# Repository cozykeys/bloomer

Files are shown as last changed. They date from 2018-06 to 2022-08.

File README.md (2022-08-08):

# CozyKeys Bloomer

This repository contains the design files for the CozyKeys Bloomer, an 87-key
ergonomic mechanical keyboard.

This keyboard has undergone several revisions and name changes. Previous names
were *Atreus87* and *Ergo87* and artifacts of these may still be present in the
repository.

Bloomer

## Firmware

- [Bloomer rev2](https://github.com/cozykeys/qmk_firmware/tree/bloomer_v2)
- [Bloomer rev3](https://github.com/cozykeys/qmk_firmware/tree/bloomer_v3)

## Project Status

### rev0

The first revision of the board was hand-wired and built as a proof of concept
to ensure that the layout is comfortable.

### rev1

The second revision added a PCB and a complete redesign of the case so that the
PCB would fit accurately.

This initial PCB was functional but lacked any RGB support. It also had a few
issues:
- When placing the ItsyBitsy upside down to reduce the height needed between
  the switch plate and bottom plate, there is no easy way to access RST
- Switch footprints were "flippable" which was misleading as the controller
  pinout only supported a single orientation

### rev2

The second revision added several features and fixes:
- Dedicated reset button with the case updated to make this accessible
- Single orientation switch footprints
- RGB underglow support

[Rev2 Build Guide](./revisions/rev2/README.md)

### rev3 (REDACTED)

See: [v3.0 README](./v3.0/README.md)

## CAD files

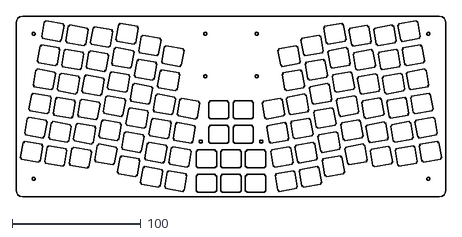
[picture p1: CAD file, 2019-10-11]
revisions/rev3.1/bloomer_switch_plate_v3_1.dxf
333.7 x 140.0

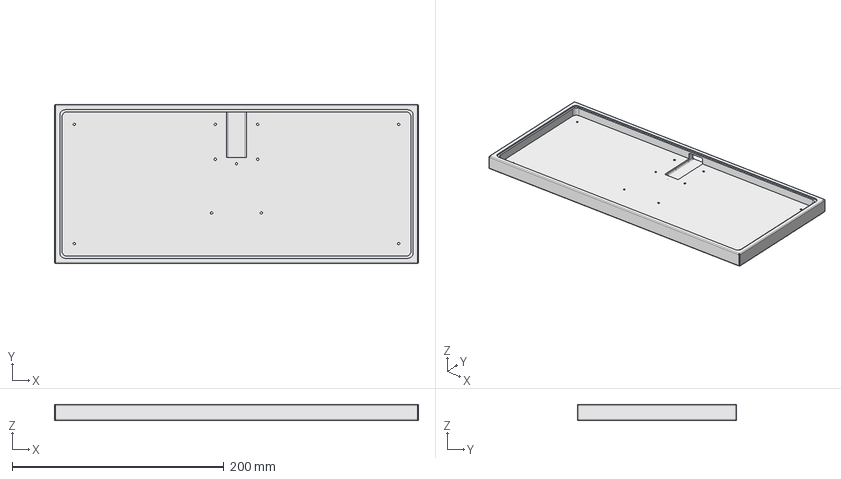
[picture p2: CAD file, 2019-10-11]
v3.0/case/bloomer_case.FCStd
344.2 x 150.5 x 15.5 mm

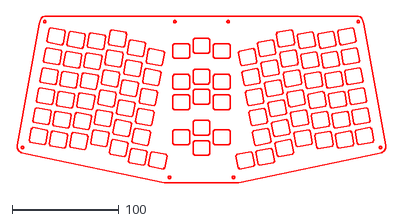
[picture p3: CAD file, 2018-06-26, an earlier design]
revisions/rev0/Sculpteo/Ergo87_Top_2.dxf
347.5 x 156.0

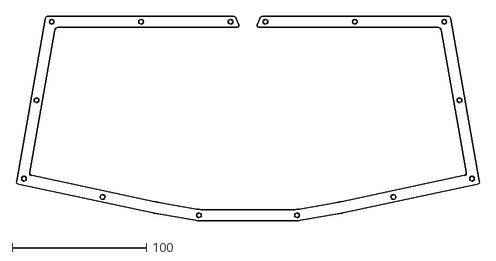
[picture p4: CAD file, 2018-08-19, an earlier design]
revisions/rev2/case_middle_plate_rev2.dxf
345.5 x 152.7

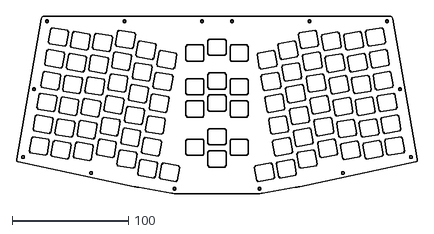
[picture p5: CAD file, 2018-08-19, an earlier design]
revisions/rev2/case_switch_plate_rev2.dxf
345.5 x 152.7

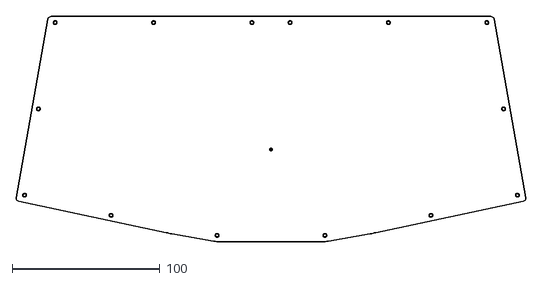
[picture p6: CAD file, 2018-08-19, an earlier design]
revisions/rev2/case_bottom_plate_rev2.dxf
345.5 x 152.7

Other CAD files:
revisions/rev3.1/bloomer_case.step
v3.0/case/case_switch_plate.dxf
revisions/rev3.1/bloomer_case.stl

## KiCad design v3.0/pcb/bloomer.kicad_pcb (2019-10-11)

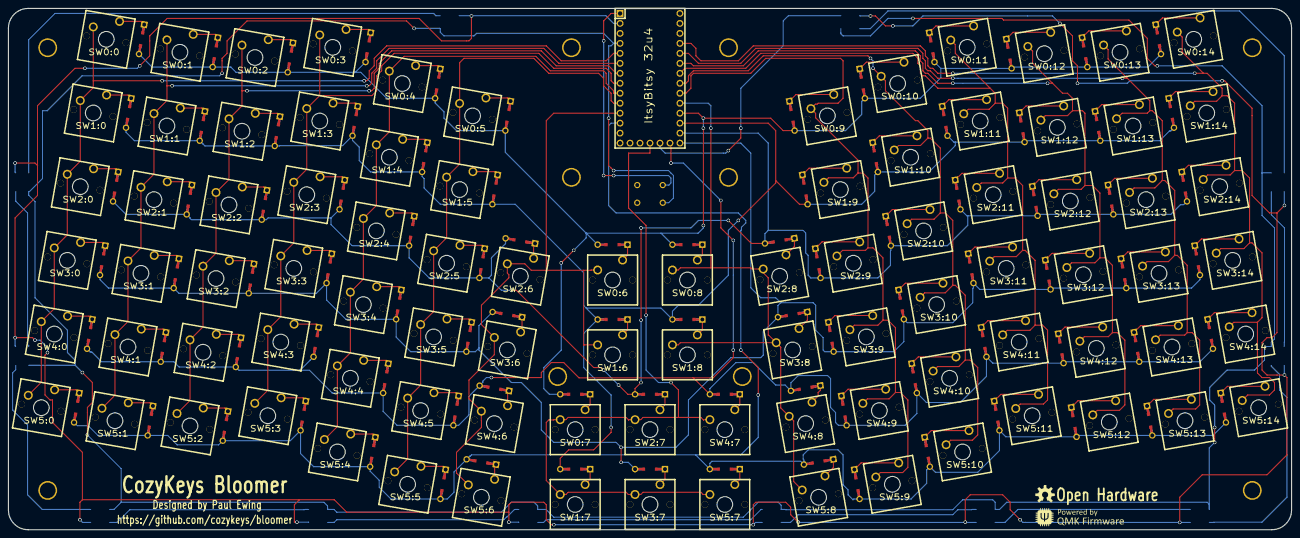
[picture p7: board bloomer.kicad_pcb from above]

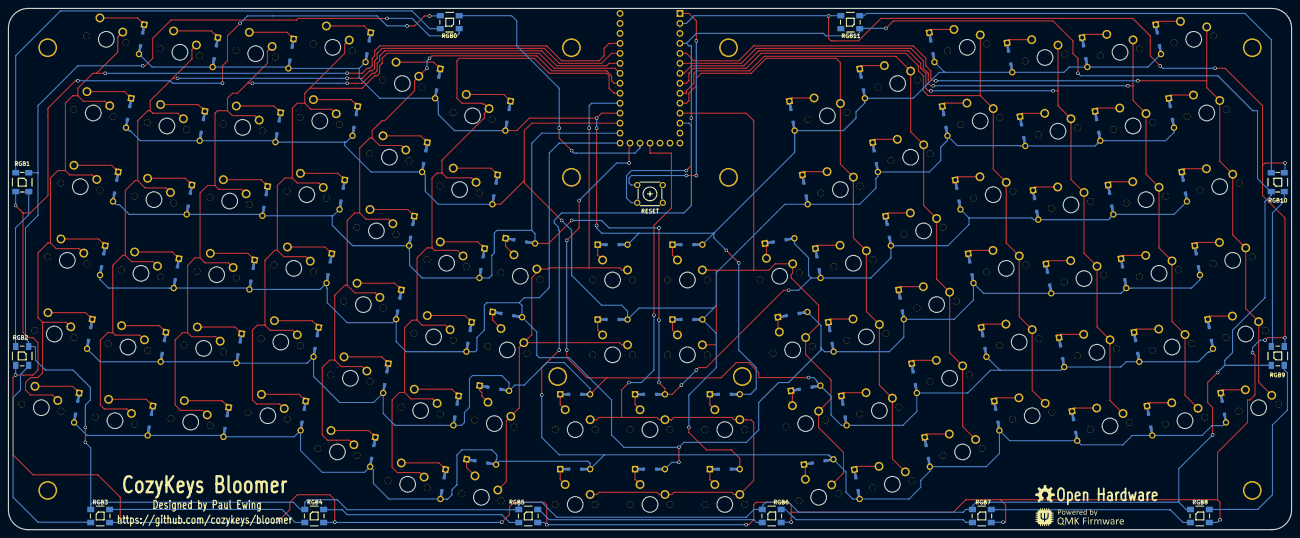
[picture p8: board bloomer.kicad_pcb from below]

Board: 2 copper layers, 326.7 x 132.7 mm, 204 parts (13 on the bottom side), 126 nets.

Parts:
D0:0, D0:1, D0:2, D0:3, D0:4, D0:5, D0:6, D0:7, D0:8, D0:9, D0:10, D0:11, D0:12, D0:13, D0:14, D1:0, D1:1, D1:2, D1:3, D1:4, D1:5, D1:6, D1:7, D1:8, D1:9, D1:10, D1:11, D1:12, D1:13, D1:14, D2:0, D2:1, D2:2, D2:3, D2:4, D2:5, D2:6, D2:7, D2:8, D2:9, D2:10, D2:11, D2:12, D2:13, D2:14, D3:0, D3:1, D3:2, D3:3, D3:4, D3:5, D3:6, D3:7, D3:8, D3:9, D3:10, D3:11, D3:12, D3:13, D3:14, D4:0, D4:1, D4:2, D4:3, D4:4, D4:5, D4:6, D4:7, D4:8, D4:9, D4:10, D4:11, D4:12, D4:13, D4:14, D5:0, D5:1, D5:2, D5:3, D5:4, D5:5, D5:6, D5:7, D5:8, D5:9, D5:10, D5:11, D5:12, D5:13, D5:14: DIODE
HOLE_M3, HOLE_M3#2, HOLE_M3#3, HOLE_M3#4, HOLE_M3#5, HOLE_M3#6, HOLE_M3#7, HOLE_M3#8, HOLE_M3#9, HOLE_M3#10: VAL**; HOLE_M3
ItsyBitsy 32u4: ItsyBitsy
RESET: VAL**; B3F-10XX
RGB0, RGB1, RGB2, RGB3, RGB4, RGB5, RGB6, RGB7, RGB8, RGB9, RGB10, RGB11: VAL**; WS2812B
SW0:0, SW0:1, SW0:2, SW0:3, SW0:4, SW0:5, SW0:6, SW0:7, SW0:8, SW0:9, SW0:10, SW0:11, SW0:12, SW0:13, SW0:14, SW1:0, SW1:1, SW1:2, SW1:3, SW1:4, SW1:5, SW1:6, SW1:7, SW1:8, SW1:9, SW1:10, SW1:11, SW1:12, SW1:13, SW1:14, SW2:0, SW2:1, SW2:2, SW2:3, SW2:4, SW2:5, SW2:6, SW2:7, SW2:8, SW2:9, SW2:10, SW2:11, SW2:12, SW2:13, SW2:14, SW3:0, SW3:1, SW3:2, SW3:3, SW3:4, SW3:5, SW3:6, SW3:7, SW3:8, SW3:9, SW3:10, SW3:11, SW3:12, SW3:13, SW3:14, SW4:0, SW4:1, SW4:2, SW4:3, SW4:4, SW4:5, SW4:6, SW4:7, SW4:8, SW4:9, SW4:10, SW4:11, SW4:12, SW4:13, SW4:14, SW5:0, SW5:1, SW5:2, SW5:3, SW5:4, SW5:5, SW5:6, SW5:7, SW5:8, SW5:9, SW5:10, SW5:11, SW5:12, SW5:13, SW5:14: MX_SWITCH

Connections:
5V: ItsyBitsy 32u4.2, RGB0.3, RGB1.3, RGB2.3, RGB3.3, RGB4.3, RGB5.3, RGB6.3, RGB7.3, RGB8.3, RGB9.3, RGB10.3, RGB11.3
GND: ItsyBitsy 32u4.4, RESET.2, RGB0.1, RGB1.1, RGB2.1, RGB3.1, RGB4.1, RGB5.1, RGB6.1, RGB7.1, RGB8.1, RGB9.1, RGB10.1, RGB11.1
N-RGB-D0: ItsyBitsy 32u4.18, RGB0.2
N-RGB-D1: RGB0.4, RGB1.2
N-RGB-D2: RGB1.4, RGB2.2
N-RGB-D3: RGB2.4, RGB3.2
N-RGB-D4: RGB3.4, RGB4.2
N-RGB-D5: RGB4.4, RGB5.2
N-RGB-D6: RGB5.4, RGB6.2
N-RGB-D7: RGB6.4, RGB7.2
N-RGB-D8: RGB7.4, RGB8.2
N-RGB-D9: RGB8.4, RGB9.2
N-RGB-D10: RGB9.4, RGB10.2
N-RGB-D11: RGB10.4, RGB11.2
N-col-0: ItsyBitsy 32u4.5, SW0:0.2, SW1:0.2, SW2:0.2, SW3:0.2, SW4:0.2, SW5:0.2
N-col-1: ItsyBitsy 32u4.6, SW0:1.2, SW1:1.2, SW2:1.2, SW3:1.2, SW4:1.2, SW5:1.2
N-col-2: ItsyBitsy 32u4.7, SW0:2.2, SW1:2.2, SW2:2.2, SW3:2.2, SW4:2.2, SW5:2.2
N-col-3: ItsyBitsy 32u4.8, SW0:3.2, SW1:3.2, SW2:3.2, SW3:3.2, SW4:3.2, SW5:3.2
N-col-4: ItsyBitsy 32u4.9, SW0:4.2, SW1:4.2, SW2:4.2, SW3:4.2, SW4:4.2, SW5:4.2
N-col-5: ItsyBitsy 32u4.10, SW0:5.2, SW1:5.2, SW2:5.2, SW3:5.2, SW4:5.2, SW5:5.2
N-col-6: ItsyBitsy 32u4.11, SW0:6.2, SW1:6.2, SW2:6.2, SW3:6.2, SW4:6.2, SW5:6.2
N-col-7: ItsyBitsy 32u4.17, SW0:7.2, SW1:7.2, SW2:7.2, SW3:7.2, SW4:7.2, SW5:7.2
N-col-8: ItsyBitsy 32u4.24, SW0:8.2, SW1:8.2, SW2:8.2, SW3:8.2, SW4:8.2, SW5:8.2
N-col-9: ItsyBitsy 32u4.25, SW0:9.2, SW1:9.2, SW2:9.2, SW3:9.2, SW4:9.2, SW5:9.2
N-col-10: ItsyBitsy 32u4.26, SW0:10.2, SW1:10.2, SW2:10.2, SW3:10.2, SW4:10.2, SW5:10.2
N-col-11: ItsyBitsy 32u4.27, SW0:11.2, SW1:11.2, SW2:11.2, SW3:11.2, SW4:11.2, SW5:11.2
N-col-12: ItsyBitsy 32u4.28, SW0:12.2, SW1:12.2, SW2:12.2, SW3:12.2, SW4:12.2, SW5:12.2
N-col-13: ItsyBitsy 32u4.29, SW0:13.2, SW1:13.2, SW2:13.2, SW3:13.2, SW4:13.2, SW5:13.2
N-col-14: ItsyBitsy 32u4.30, SW0:14.2, SW1:14.2, SW2:14.2, SW3:14.2, SW4:14.2, SW5:14.2
N-diode-0-0: D0:0.2, SW0:0.1
N-diode-0-1: D0:1.2, SW0:1.1
N-diode-0-2: D0:2.2, SW0:2.1
N-diode-0-3: D0:3.2, SW0:3.1
N-diode-0-4: D0:4.2, SW0:4.1
N-diode-0-5: D0:5.2, SW0:5.1
N-diode-0-6: D0:6.2, SW0:6.1
N-diode-0-7: D0:7.2, SW0:7.1
N-diode-0-8: D0:8.2, SW0:8.1
N-diode-0-9: D0:9.2, SW0:9.1
N-diode-0-10: D0:10.2, SW0:10.1
N-diode-0-11: D0:11.2, SW0:11.1
N-diode-0-12: D0:12.2, SW0:12.1
N-diode-0-13: D0:13.2, SW0:13.1
N-diode-0-14: D0:14.2, SW0:14.1
N-diode-1-0: D1:0.2, SW1:0.1
N-diode-1-1: D1:1.2, SW1:1.1
N-diode-1-2: D1:2.2, SW1:2.1
N-diode-1-3: D1:3.2, SW1:3.1
N-diode-1-4: D1:4.2, SW1:4.1
N-diode-1-5: D1:5.2, SW1:5.1
N-diode-1-6: D1:6.2, SW1:6.1
N-diode-1-7: D1:7.2, SW1:7.1
N-diode-1-8: D1:8.2, SW1:8.1
N-diode-1-9: D1:9.2, SW1:9.1
N-diode-1-10: D1:10.2, SW1:10.1
N-diode-1-11: D1:11.2, SW1:11.1
N-diode-1-12: D1:12.2, SW1:12.1
N-diode-1-13: D1:13.2, SW1:13.1
N-diode-1-14: D1:14.2, SW1:14.1
N-diode-2-0: D2:0.2, SW2:0.1
N-diode-2-1: D2:1.2, SW2:1.1
N-diode-2-2: D2:2.2, SW2:2.1
N-diode-2-3: D2:3.2, SW2:3.1
N-diode-2-4: D2:4.2, SW2:4.1
N-diode-2-5: D2:5.2, SW2:5.1
N-diode-2-6: D2:6.2, SW2:6.1
N-diode-2-7: D2:7.2, SW2:7.1
N-diode-2-8: D2:8.2, SW2:8.1
N-diode-2-9: D2:9.2, SW2:9.1
N-diode-2-10: D2:10.2, SW2:10.1
N-diode-2-11: D2:11.2, SW2:11.1
N-diode-2-12: D2:12.2, SW2:12.1
N-diode-2-13: D2:13.2, SW2:13.1
N-diode-2-14: D2:14.2, SW2:14.1
N-diode-3-0: D3:0.2, SW3:0.1
N-diode-3-1: D3:1.2, SW3:1.1
N-diode-3-2: D3:2.2, SW3:2.1
N-diode-3-3: D3:3.2, SW3:3.1
N-diode-3-4: D3:4.2, SW3:4.1
N-diode-3-5: D3:5.2, SW3:5.1
N-diode-3-6: D3:6.2, SW3:6.1
N-diode-3-7: D3:7.2, SW3:7.1
N-diode-3-8: D3:8.2, SW3:8.1
N-diode-3-9: D3:9.2, SW3:9.1
N-diode-3-10: D3:10.2, SW3:10.1
N-diode-3-11: D3:11.2, SW3:11.1
N-diode-3-12: D3:12.2, SW3:12.1
N-diode-3-13: D3:13.2, SW3:13.1
N-diode-3-14: D3:14.2, SW3:14.1
N-diode-4-0: D4:0.2, SW4:0.1
N-diode-4-1: D4:1.2, SW4:1.1
N-diode-4-2: D4:2.2, SW4:2.1
N-diode-4-3: D4:3.2, SW4:3.1
N-diode-4-4: D4:4.2, SW4:4.1
N-diode-4-5: D4:5.2, SW4:5.1
N-diode-4-6: D4:6.2, SW4:6.1
N-diode-4-7: D4:7.2, SW4:7.1
N-diode-4-8: D4:8.2, SW4:8.1
N-diode-4-9: D4:9.2, SW4:9.1
N-diode-4-10: D4:10.2, SW4:10.1
N-diode-4-11: D4:11.2, SW4:11.1
N-diode-4-12: D4:12.2, SW4:12.1
N-diode-4-13: D4:13.2, SW4:13.1
N-diode-4-14: D4:14.2, SW4:14.1
N-diode-5-0: D5:0.2, SW5:0.1
N-diode-5-1: D5:1.2, SW5:1.1
N-diode-5-2: D5:2.2, SW5:2.1
N-diode-5-3: D5:3.2, SW5:3.1
N-diode-5-4: D5:4.2, SW5:4.1
N-diode-5-5: D5:5.2, SW5:5.1
N-diode-5-6: D5:6.2, SW5:6.1
N-diode-5-7: D5:7.2, SW5:7.1
N-diode-5-8: D5:8.2, SW5:8.1
N-diode-5-9: D5:9.2, SW5:9.1
N-diode-5-10: D5:10.2, SW5:10.1
N-diode-5-11: D5:11.2, SW5:11.1
N-diode-5-12: D5:12.2, SW5:12.1
N-diode-5-13: D5:13.2, SW5:13.1
N-diode-5-14: D5:14.2, SW5:14.1
N-row-0: D0:0.1, D0:1.1, D0:2.1, D0:3.1, D0:4.1, D0:5.1, D0:6.1, D0:7.1, D0:8.1, D0:9.1, D0:10.1, D0:11.1, D0:12.1, D0:13.1, D0:14.1, ItsyBitsy 32u4.23
N-row-1: D1:0.1, D1:1.1, D1:2.1, D1:3.1, D1:4.1, D1:5.1, D1:6.1, D1:7.1, D1:8.1, D1:9.1, D1:10.1, D1:11.1, D1:12.1, D1:13.1, D1:14.1, ItsyBitsy 32u4.22
N-row-2: D2:0.1, D2:1.1, D2:2.1, D2:3.1, D2:4.1, D2:5.1, D2:6.1, D2:7.1, D2:8.1, D2:9.1, D2:10.1, D2:11.1, D2:12.1, D2:13.1, D2:14.1, ItsyBitsy 32u4.21
N-row-3: D3:0.1, D3:1.1, D3:2.1, D3:3.1, D3:4.1, D3:5.1, D3:6.1, D3:7.1, D3:8.1, D3:9.1, D3:10.1, D3:11.1, D3:12.1, D3:13.1, D3:14.1, ItsyBitsy 32u4.20
N-row-4: D4:0.1, D4:1.1, D4:2.1, D4:3.1, D4:4.1, D4:5.1, D4:6.1, D4:7.1, D4:8.1, D4:9.1, D4:10.1, D4:11.1, D4:12.1, D4:13.1, D4:14.1, ItsyBitsy 32u4.19
N-row-5: D5:0.1, D5:1.1, D5:2.1, D5:3.1, D5:4.1, D5:5.1, D5:6.1, D5:7.1, D5:8.1, D5:9.1, D5:10.1, D5:11.1, D5:12.1, D5:13.1, D5:14.1, ItsyBitsy 32u4.12
RST: ItsyBitsy 32u4.1, RESET.1

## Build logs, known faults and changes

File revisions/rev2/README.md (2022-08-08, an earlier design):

# Bloomer v2 Keyboard Build Guide

bloomer keyboard

## **Materials:**

 - Soldering Iron + Solder
 - 1N4148 Diodes ([example](https://www.mouser.com/ProductDetail/onsemi-Fairchild/1N4148?qs=i4Fj9T/oRm8RMUhj5DeFQg==))
 - ([Microcontroller](https://www.adafruit.com/product/3677)) 
 - Printed PCB
 - Laser cut case (3 pieces)
 - 12mm M2 standoffs
 - M2 screw heads
 - 6mm x 6mm reset button ([example](https://www.digikey.com/en/products/detail/omron-electronics-inc-emc-div/B3F-1000/33150))
 - Key switches of your choosing
 - Key caps ([key caps shown in photo](https://pimpmykeyboard.com/dsa-standard-keysets-sublimated/))
 - (Optional) WS2812b RGB LEDs

## **Steps**:

1) Obtain all the materials listed above. You can use services like https://ponoko.com to print the case pieces and you can use services like https://jlcpcb.com/ to print the PCB. Just upload the respective files to the site and follow the steps to order them.

2) Solder diodes and clip legs off before anything else. Make sure they are all soldered in the same orientation. One side of the diode should have a ring around it and should be facing DOWN. All of the diodes should be on the back side of the PCB (the side with the Bloomer/Ergo87 text on it) **except for one mentioned in step 3**.

3) One switch and diode are soldered onto the PCB above the microcontroller so **both the switch and diode need to be soldered BEFORE the microcontroller**. This is the only diode that is horizontal and should be the only one on the front side of the PCB, same side that the switch is seated on. The ring side of the diode should be to the left (Q side on a qwerty keyboard). Triple check that this specific diode and switch are soldered correctly because removing a microcontroller to fix it is a nightmare.

4) Solder the reset button. There is an external reset button (part number B3F-1000 Omron tactical switch) located dead center on the back side of the PCB indicated by a (+) icon. This is because the microcontroller is mounted upside down so the built-in reset button is inaccessible. This technically isn't necessary because you can reset the controller by simply touching the RST and GND pins together with a loose wire but that's not fun to do every time you want to adjust your QMK layout. It is highly recommended to add this for easily resetting the firmware.

5) Mount switches into the plate and solder them. It is recommended that you don't try to put all of the switches into the plate before soldering, especially if using PCB mount. Clip one switch into the plate at a time, seat it completely into the PCB, and solder. Rinse repeat. It is recommended to do all the corners first and and from there the order doesn't really matter.

6) Solder the microcontroller pin headers. You will need to clip off the long pin headers to be flush with the microcontroller. (See the Speedo build guide for tips on how to do this:  [https://github.com/cozykeys/speedo/blob/master/build_guide.md#microcontroller](https://github.com/cozykeys/speedo/blob/master/build_guide.md#microcontroller))

7) Optionally solder on WS2812b RGB LEDs in the designated areas on the edge of the PCB. There are a total of 12.

8) Flash QMK firmware and test the keyboard, and fix any keys that don't work due to bad solder joints. To flash the firmware, visit https://config.qmk.fm/#/cozykeys/bloomer/v2/LAYOUT, customize key layout to your liking, click compile, once it is done, download the firmware. Then, use QMK Toolbox to flash the firmware to your keyboard. Note: you may have to hit the reset button twice before flashing the firmware.

9) Close up the case using the printed components and the 12mm M2 brass standoffs and screws like these:
	 - [https://www.ebay.com/itm/293622150636](https://www.ebay.com/itm/293622150636)  
	 - [https://www.ebay.com/itm/174331139173](https://www.ebay.com/itm/174331139173)

Some pictures to clarify steps above:  [https://imgur.com/a/y5eZmY8](https://imgur.com/a/y5eZmY8)

For more information about the Bloomer keyboard, visit https://cozykeys.xyz/keyboards/bloomer.

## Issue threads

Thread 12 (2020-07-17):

Gerber Files rev2 not working

spicajames, 2020-07-17:
Please check rev 2 gerber zip file, it looks corrupt

spicajames, 2020-07-17:
I just downloaded and double click on win10, I also tried to uncompress with 7zip. Non worked.
Rev 1 file works just fine. Maybe just upload it again will do the trick.

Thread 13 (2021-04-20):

No schematic in PCB files

properlypurple, 2021-04-20:
I was looking to make small modifications to the PCB layout, but it looks like the schematic file is missing, and can't be generated because of missing libraries(I have all libraries installed)

pcewing, 2021-04-21:
Hi @properlypurple! Thanks for the interest in the project.

Unfortunately, at the time when I designed the Bloomer I was still very new to electronics and didn't understand the importance of a schematic so I just auto-generated the `kicad_pcb` file directly using code. So, there is currently no schematic file for v2 or v3 and I don't have plans to create one.

In my latest projects I actually have used a schematic and when I get around to finishing the next version (v4) of the Bloomer, it will have one. I just started actively working on that but it could be a while yet until I complete it.

properlypurple, 2021-04-21:
Thank you for responding @pcewing . If you don't mind sharing, what kind of code did you use to auto-generate the pcb file? I really like the layout, but an itsy-bitsy is hard to source where I live, and I would like to modify it a bit for another board(STM32F401 blackpill). Otherwise I'd just to have to brute force the connections manually, which is exhausting.

pcewing, 2021-04-21:
Yep, but I should warn you first that I haven't touched this code in a long time and it's a bit of a mess. I've since moved away from doing things this way in favor of using schematics. I'm still happy to answer questions but it may be difficult to get this working again.

It's a C# .NET Core app and it's on GitHub here:
https://github.com/cozykeys/resources/tree/master/kbutil

Once you have the .NET Core SDK installed, to build it:
```bash
git clone https://github.com/cozykeys/resources
cd resources/kbutil
make
```

The command that handles PCB generation is `gen-pcb` so after building, you'd run the tool like:
```bash
build/KbUtil.Console/bin/Release/kbutil gen-pcb bloomer <input-path> <output-path>
```

The code executing that command lives here:
https://github.com/cozykeys/resources/blob/master/kbutil/src/KbUtil.Console/Commands/GeneratePcbCommand.cs

And all of the underlying code to generate the `kicad_pcb` file lives in this library:
https://github.com/cozykeys/resources/tree/master/kbutil/src/KbUtil.Lib/PcbGeneration

The summary of how it works is that it's a very basic template generation system. So it reads "template" files and does basic substitution of values.

properlypurple, 2021-04-22:
Thanks! That is helpful. I'll go ahead and close this, since this is not in scope for the current version anyway

Closed 2021-04-22.

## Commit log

2018-06-26 Make some major updates
    * Refactored some of the models
    * Refactored Deserialization
    * Added support for constants in the data file
    * Added support for layers in the data file
    [Atreus87_Top_2.dxf]
2018-07-18 Rename files
    [Ergo87_Top_2.dxf]
2018-07-18 Move kbutil to its own repository
    [Ergo87_Top_2.dxf]
2018-08-05 First revision of a PCB
    Also redesigned the case to better fit the PCB.
    [Ergo87_Top_2.dxf, ergo87.kicad_pcb]
2018-08-17 Add reset button footprint
    [ergo87.kicad_pcb]
2018-08-18 Start working on RGB underglow support
    [ergo87.kicad_pcb]
2018-08-18 Finish the rev2 features
    [ergo87.kicad_pcb]
2018-08-18 Add DXF files
    [case_bottom_plate_rev2.dxf, case_middle_plate_rev2.dxf, case_switch_plate_rev2.dxf]
2018-09-12 Rename Ergo87 to Bloomer and update readme
    [bloomer.kicad_pcb]
